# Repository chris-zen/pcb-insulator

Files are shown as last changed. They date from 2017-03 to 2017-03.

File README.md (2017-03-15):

# PCB Insulator

This project contains the design ideas to build a PCB insulator using UV LEDS.

The design is for a board of 100x75 mm, but you can compose several boards to increase the exposure surface. Just remember that you will need to use the appropriate power supply. I include some numbers to help with this.

# Numbers per board

LED specs: 3.3V 20mA

Voltage across resistor = 12V - (3 * 3.2V) = 2.4V

Resistor value = 2.4V / 0.02A = 120 Ohm

Power dissipated by resistor = 2.4V * 0.02A = 0.048 W = 48 mW

Power consumed by LED = 3.2V * 0.02A = 0.064W = 64mW

1 Board contains 16 resistors and 48 LEDs

Total power dissipated by resistors = 16 * 0.048W = 0.768W

Total power consumed by LEDs = 48 * 0.064W = 3.072W

**Total power = 0.768W + 3.072W = 3.84W**

**Total current consumption = 3.84W / 12V = 0.32A**

If you compose 4 boards you would need a power supply supporting 15.36W and 1.28A

# References

I have based my design on those other projects:

- http://www.instructables.com/id/Arduino-controlled-UV-LED-PCB-Exposure-Box/?ALLSTEPS
- http://www.carlolog.net/log/2012/09/making-an-uv-exposure-box-from-scratch/
- http://www.electronics-lab.com/project/led-uv-exposure-box/

# Part list

- [LEDs UV](https://www.amazon.es/gp/product/B01ANW9ZX2/ref=ox_sc_act_title_2?ie=UTF8&psc=1&smid=A1DMSD13LMYETC).
- [Power supply](https://www.amazon.es/gp/product/B01GC5QQ1I/ref=oh_aui_detailpage_o00_s01?ie=UTF8&psc=1)
- 100x75mm single layer PCB
- 120 Ohm 1/4W resistors

# Photos

https://goo.gl/photos/k7TKoiVqc2WFZSGJ9

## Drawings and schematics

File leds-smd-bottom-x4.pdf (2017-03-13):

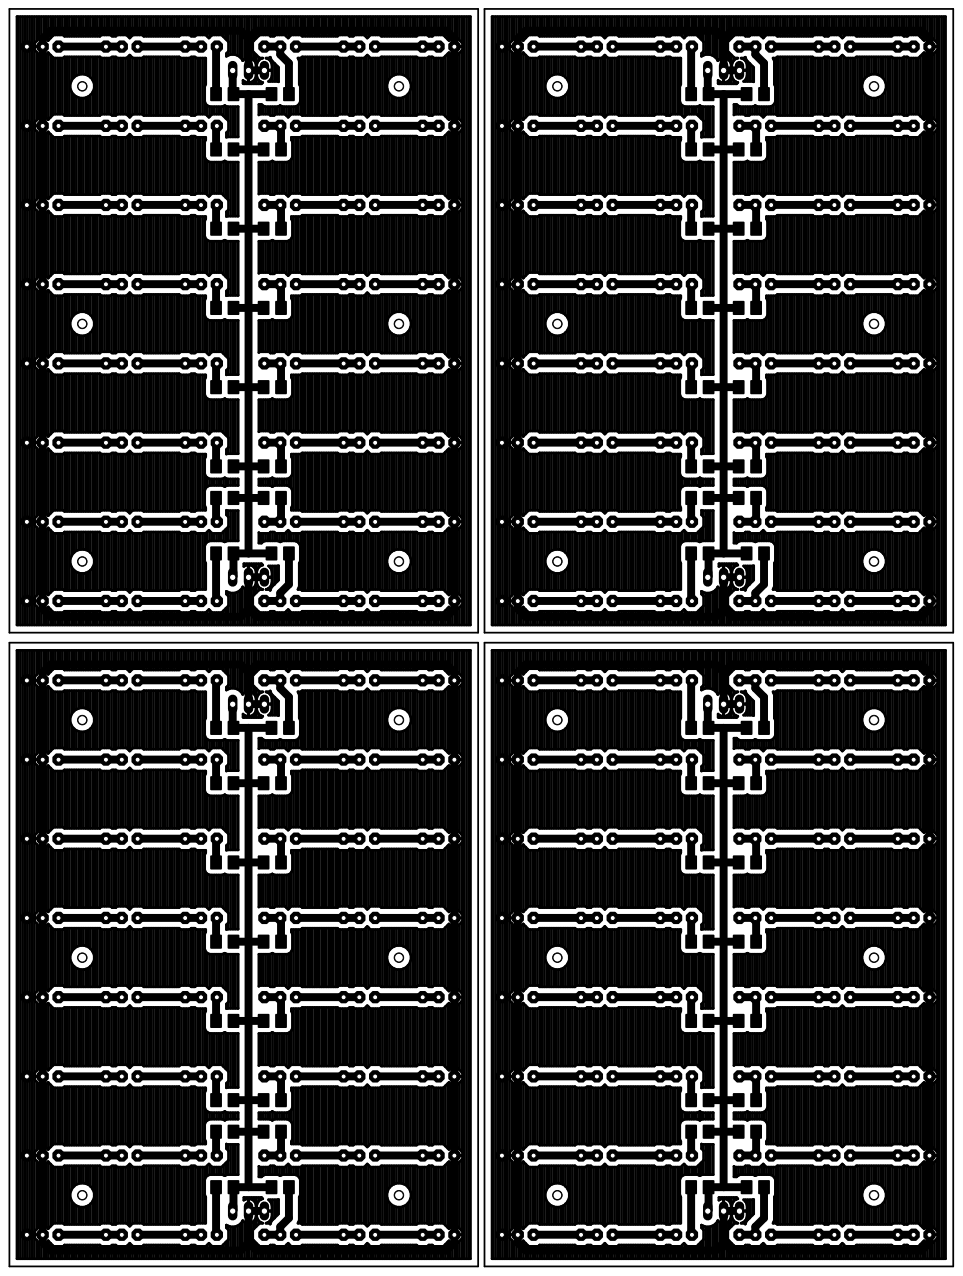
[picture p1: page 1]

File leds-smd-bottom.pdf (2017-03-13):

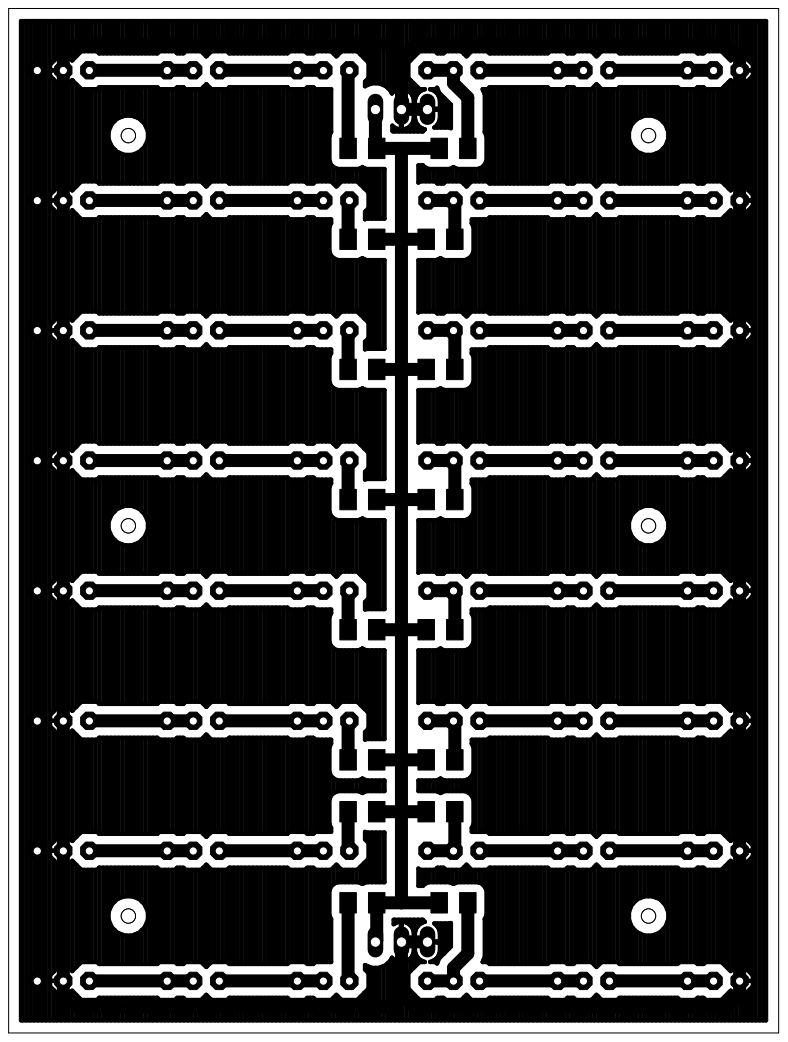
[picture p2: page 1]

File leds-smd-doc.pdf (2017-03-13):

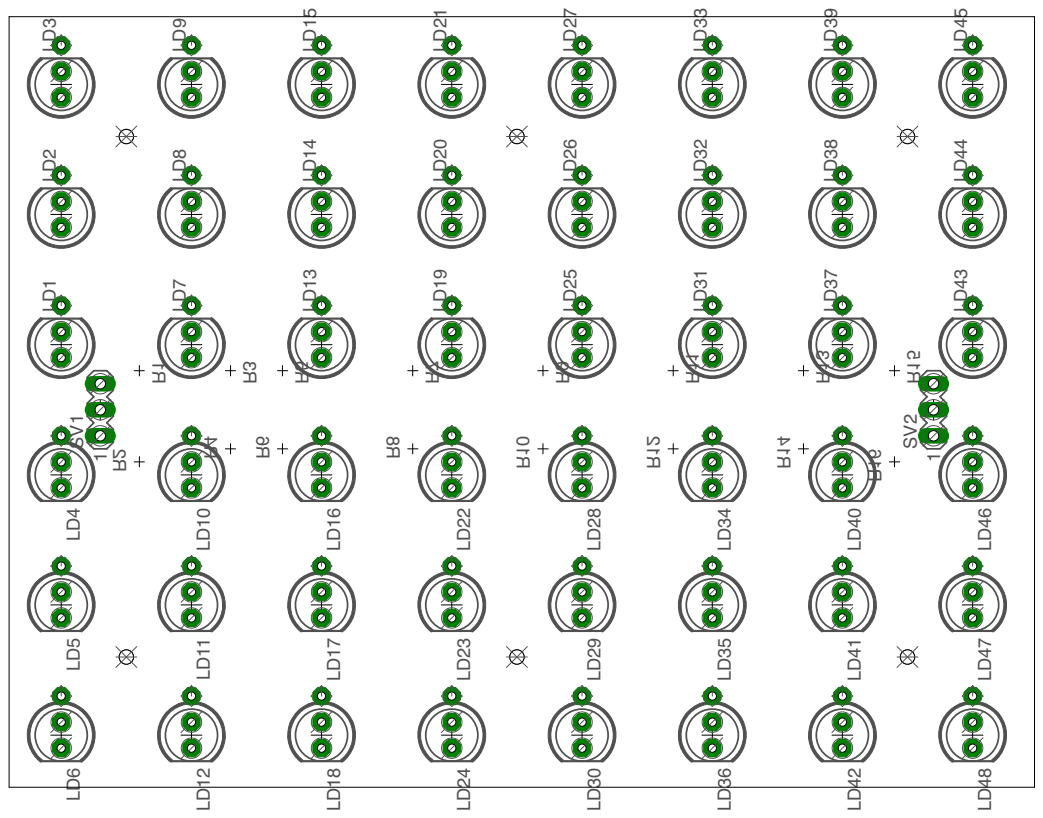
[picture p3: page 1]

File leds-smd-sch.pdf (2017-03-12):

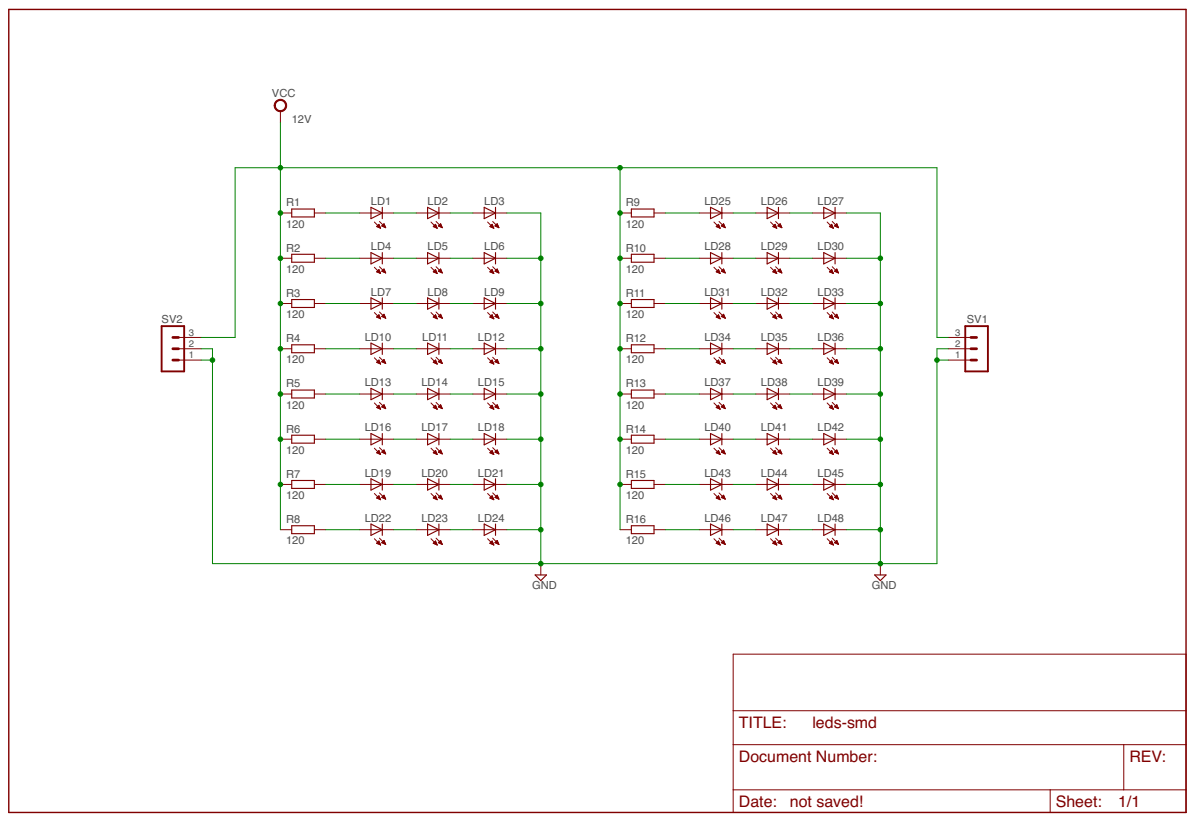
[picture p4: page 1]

Document Number: | REV:

Date: not saved! | Sheet: 1/1

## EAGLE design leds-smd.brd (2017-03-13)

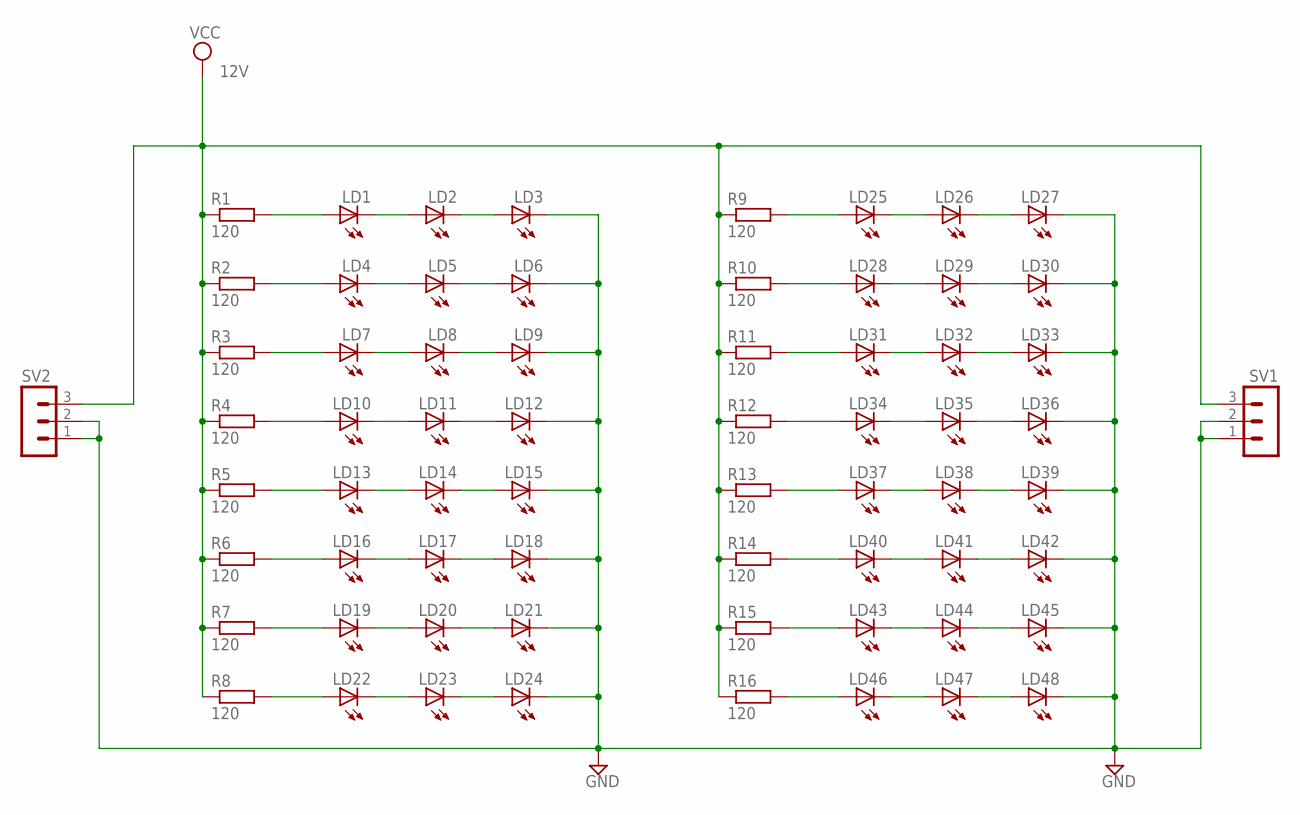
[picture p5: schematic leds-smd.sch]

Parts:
LD1, LD2, LD3, LD4, LD5, LD6, LD7, LD8, LD9, LD10, LD11, LD12, LD13, LD14, LD15, LD16, LD17, LD18, LD19, LD20, LD21, LD22, LD23, LD24, LD25, LD26, LD27, LD28, LD29, LD30, LD31, LD32, LD33, LD34, LD35, LD36, LD37, LD38, LD39, LD40, LD41, LD42, LD43, LD44, LD45, LD46, LD47, LD48: LED5MM
R1, R2, R3, R4, R5, R6, R7, R8, R9, R10, R11, R12, R13, R14, R15, R16: 120; M1206
SV1, SV2: MA03-1

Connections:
GND: LD3.K (C), LD6.K (C), LD9.K (C), LD12.K (C), LD15.K (C), LD18.K (C), LD21.K (C), LD24.K (C), LD27.K (C), LD30.K (C), LD33.K (C), LD36.K (C), LD39.K (C), LD42.K (C), LD45.K (C), LD48.K (C), SV1.1, SV1.2, SV2.1, SV2.2
unnamed: LD43.A, R15.2
unnamed: LD1.A, R1.2
unnamed: LD4.A, R2.2
unnamed: LD7.A, R3.2
unnamed: LD10.A, R4.2
unnamed: LD13.A, R5.2
unnamed: LD16.A, R6.2
unnamed: LD19.A, R7.2
unnamed: LD43.K (C), LD44.A
unnamed: LD1.K (C), LD2.A
unnamed: LD2.K (C), LD3.A
unnamed: LD5.K (C), LD6.A
unnamed: LD4.K (C), LD5.A
unnamed: LD7.K (C), LD8.A
unnamed: LD8.K (C), LD9.A
unnamed: LD44.K (C), LD45.A
unnamed: LD10.K (C), LD11.A
unnamed: LD11.K (C), LD12.A
unnamed: LD14.K (C), LD15.A
unnamed: LD13.K (C), LD14.A
unnamed: LD16.K (C), LD17.A
unnamed: LD17.K (C), LD18.A
unnamed: LD20.K (C), LD21.A
unnamed: LD19.K (C), LD20.A
unnamed: LD46.A, R16.2
unnamed: LD46.K (C), LD47.A
unnamed: LD22.A, R8.2
unnamed: LD25.A, R9.2
unnamed: LD28.A, R10.2
unnamed: LD31.A, R11.2
unnamed: LD34.A, R12.2
unnamed: LD37.A, R13.2
unnamed: LD40.A, R14.2
unnamed: LD22.K (C), LD23.A
unnamed: LD23.K (C), LD24.A
unnamed: LD26.K (C), LD27.A
unnamed: LD25.K (C), LD26.A
unnamed: LD28.K (C), LD29.A
unnamed: LD29.K (C), LD30.A
unnamed: LD32.K (C), LD33.A
unnamed: LD31.K (C), LD32.A
unnamed: LD34.K (C), LD35.A
unnamed: LD37.K (C), LD38.A
unnamed: LD40.K (C), LD41.A
unnamed: LD35.K (C), LD36.A
unnamed: LD38.K (C), LD39.A
unnamed: LD41.K (C), LD42.A
unnamed: LD47.K (C), LD48.A
VCC: R1.1, R2.1, R3.1, R4.1, R5.1, R6.1, R7.1, R8.1, R9.1, R10.1, R11.1, R12.1, R13.1, R14.1, R15.1, R16.1, SV1.3, SV2.3

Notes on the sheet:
12V

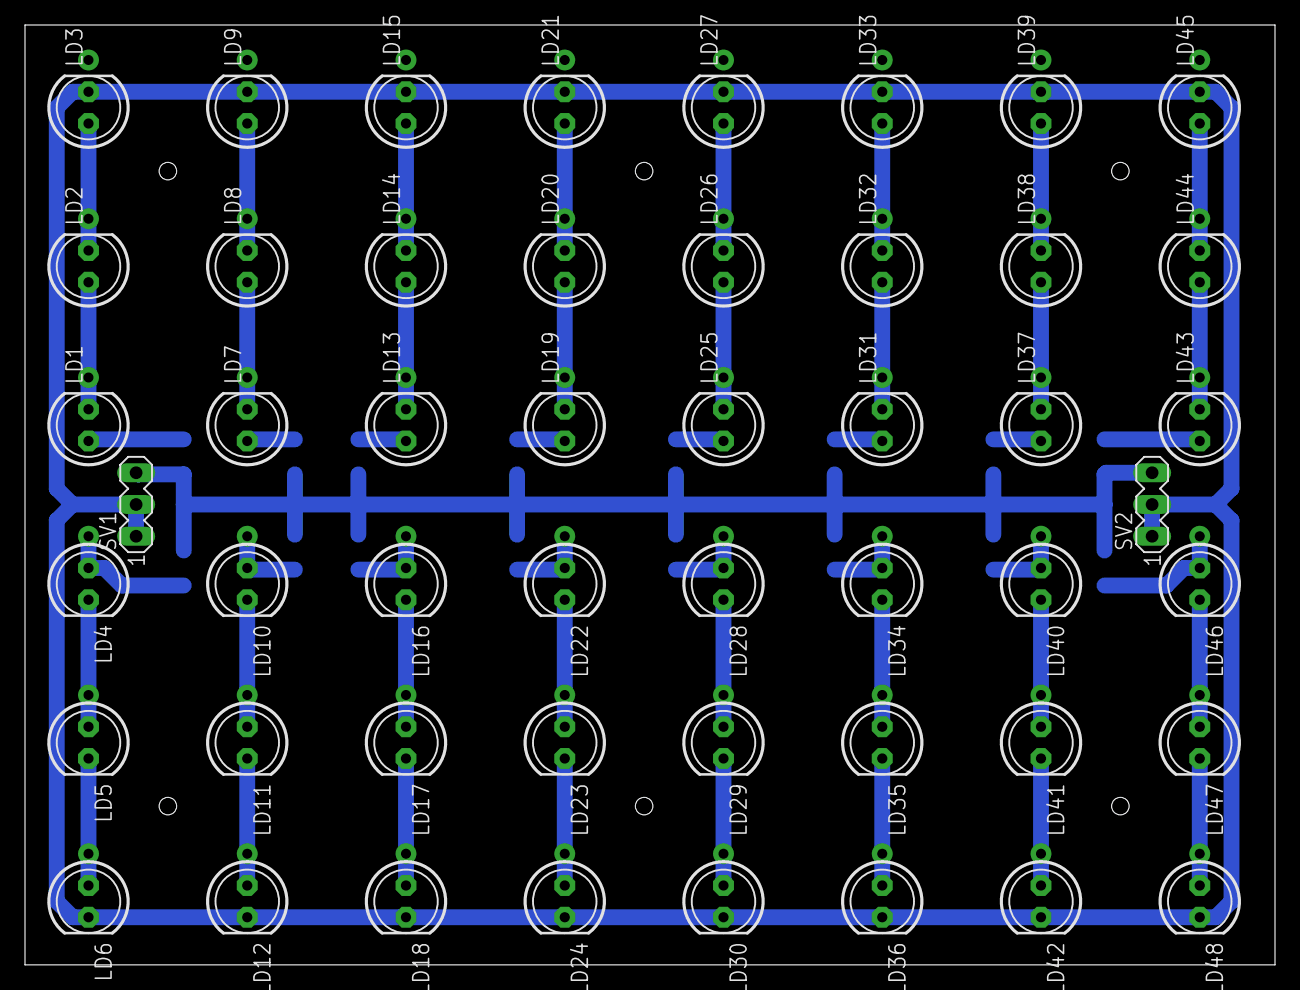
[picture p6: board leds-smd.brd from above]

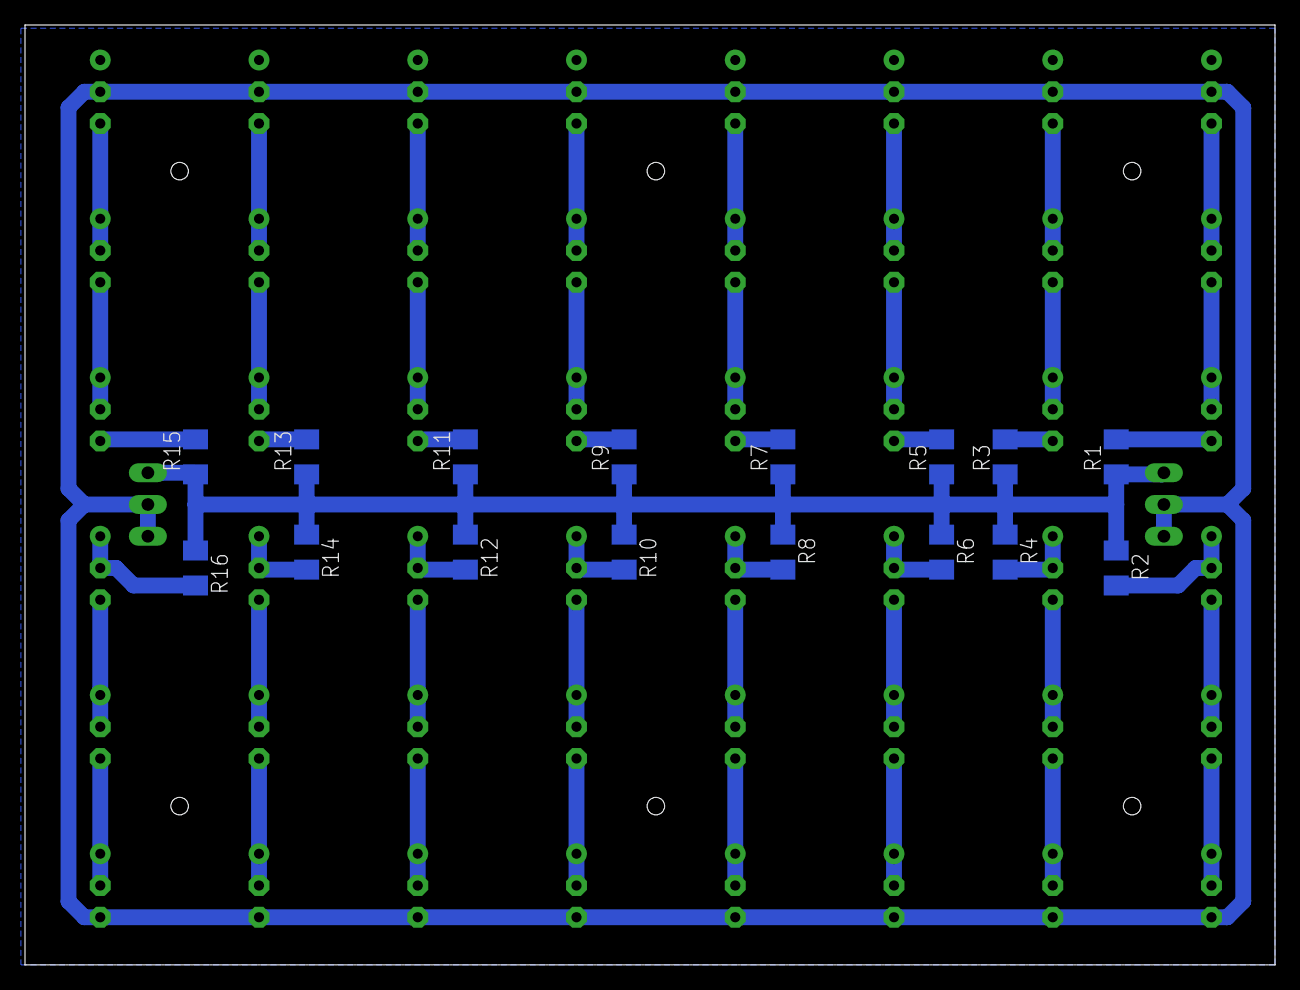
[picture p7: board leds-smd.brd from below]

Board: 2 copper layers, 100.0 x 75.2 mm, 66 parts (16 on the bottom side), 50 nets.

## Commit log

2017-03-12 Initial design
    [leds-smd.brd, leds-smd.sch, leds.brd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]
2017-03-13 Added support for 5mm leds
    [leds-smd.brd, leds-smd.sch]
